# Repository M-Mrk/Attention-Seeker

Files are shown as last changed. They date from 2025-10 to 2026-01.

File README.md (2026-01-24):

# Attention-Seeker
## Overview
A multifunctional desk peripheral designed to display and alert you to notifications.

Attention-Seeker receives notifications from a companion app and displays them on its 2.8" color screen, with optional visual and audible alerts. It also features a rotary encoder and three mechanical keyboard switches for user input (no touch!).

In addition to notification-related features, it functions as a **clock**, **desk light**, and **macropad**.

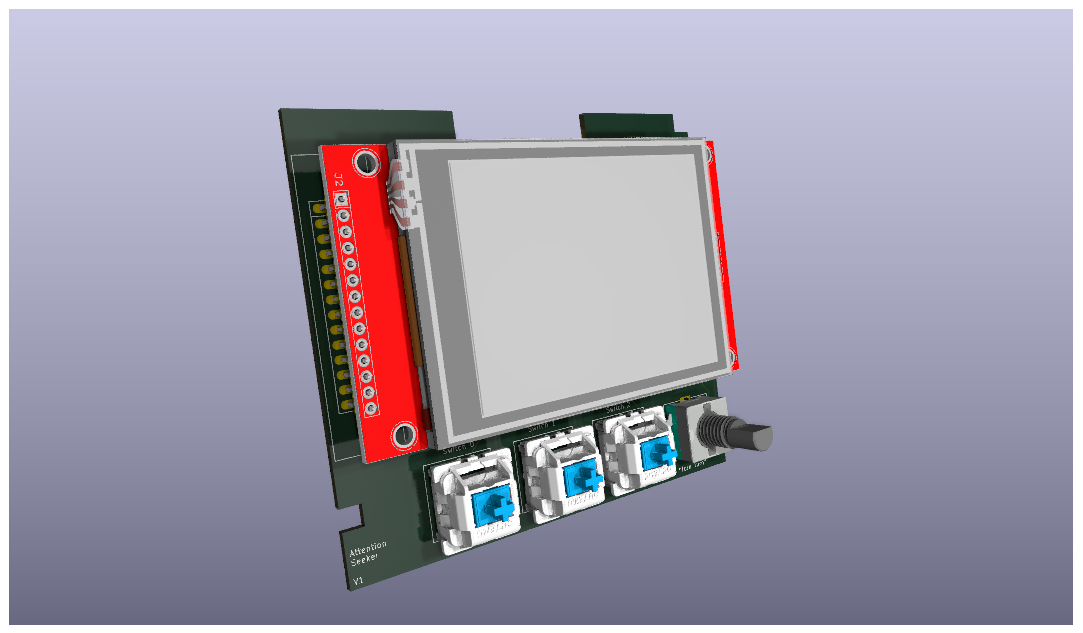
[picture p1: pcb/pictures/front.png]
Front View
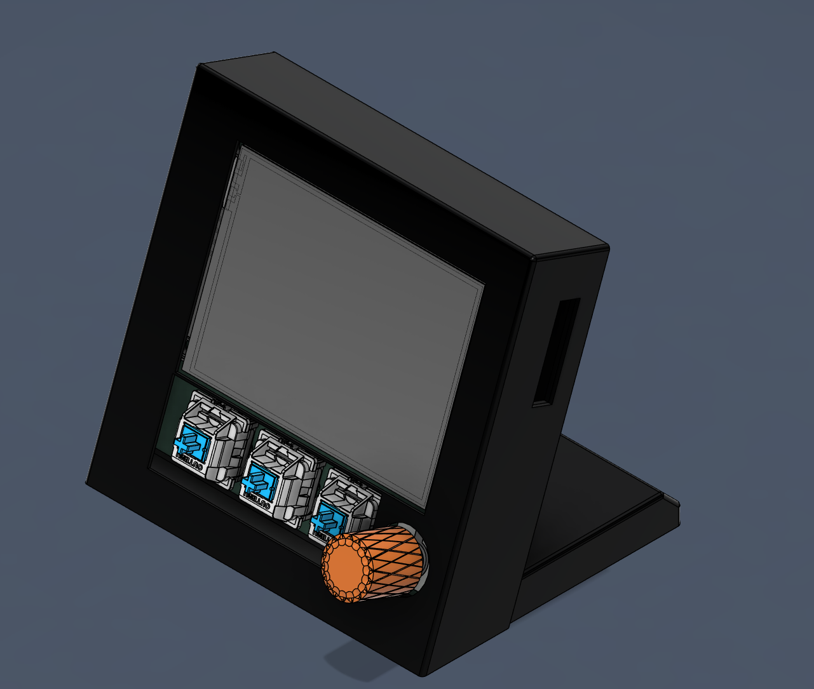
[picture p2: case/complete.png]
Semi-Assembled
 

### Why?
I often missed important notifications while zoning out or concentrating and also needed a desk light, so I built this.

### How?
- 2.8" TFT screen
- 3 mechanical keyboard switches
- Rotary encoder
- Rigid LED filament
- Buzzer
- ESP32-S3 DevKitC N16R8 CP2102
- Python companion app to run on a PC

### Example Use Cases
- **Notification:** Attention-Seeker buzzes, blinks, and displays the message.
- **Desk Light:** Toggle and dim the built-in LED for illumination.

## Features

### Notifications
Displays incoming notifications sent by the companion app with optional blinking or buzzing.

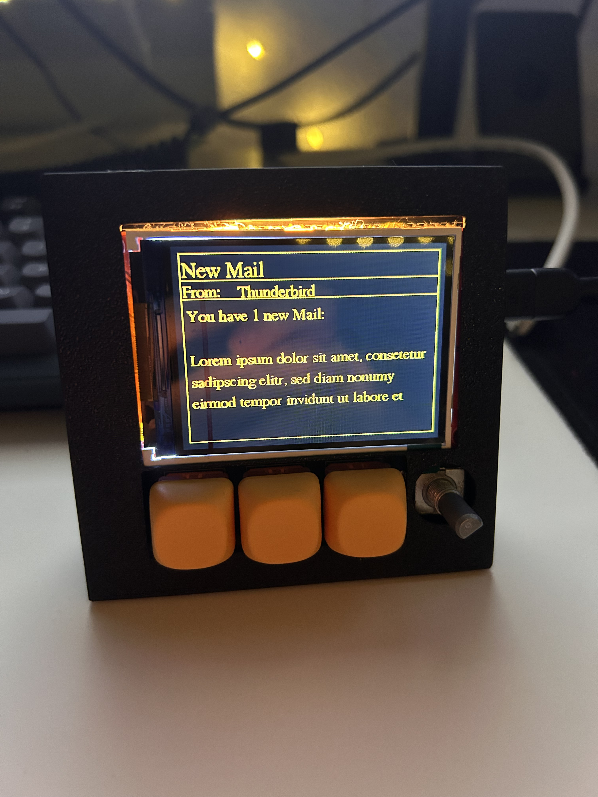
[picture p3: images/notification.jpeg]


### Clock
- Displays time
- Synced via the companion app

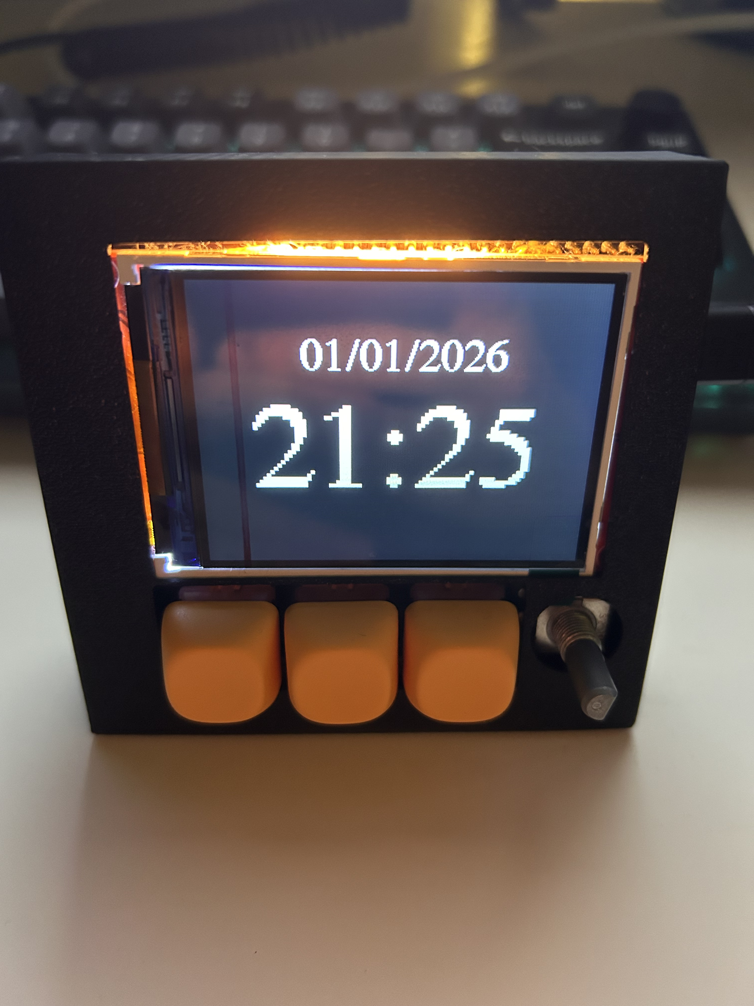
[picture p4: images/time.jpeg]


### Macropad
- 6 hotkeys

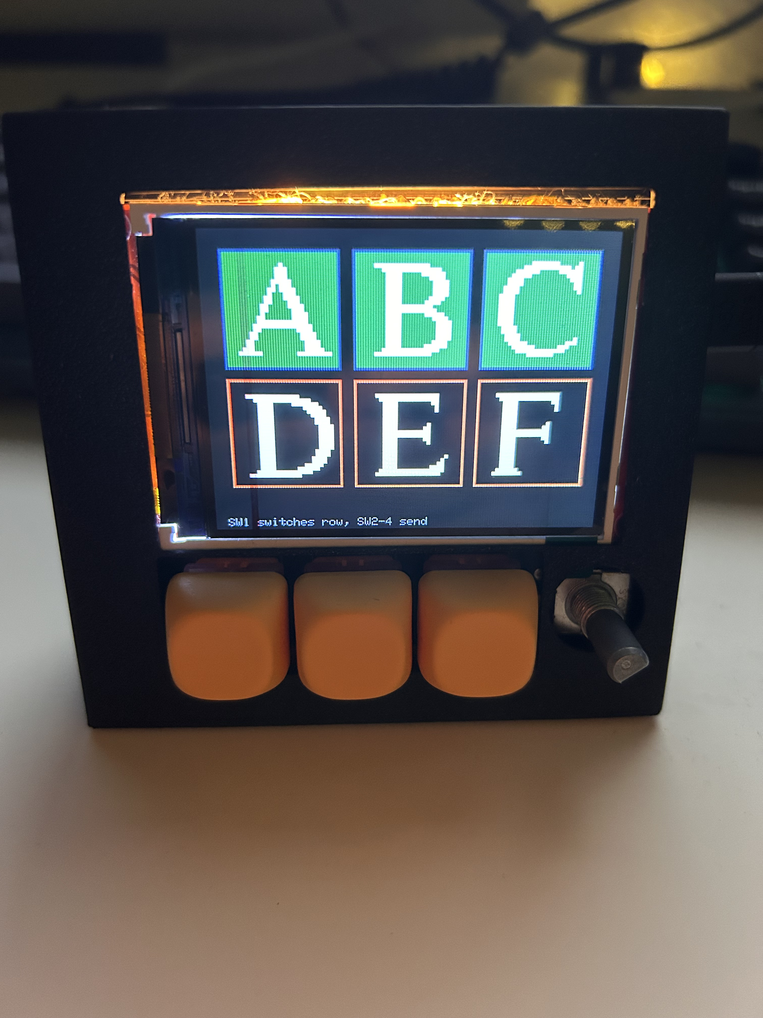
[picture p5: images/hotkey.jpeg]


### Navigation
- Mechanical keyboard switches for on-page actions
- Rotary encoder for switching between pages

### Other Features
- Dimmable desk light
- Buzzer for alerts

## Hardware

### MCU
The ESP32-S3 might be overkill but is ideal for handling the screen's pixel density, enabling fast page switching. Almost all pins are utilized, as the SPI interface for the screen consumes the majority of them.

### Lighting

#### LED Filament
The 3V filament draws about 100mA, requiring a 5V-to-3.3V LDO for power. An N-channel MOSFET drives the negative side of the LED filament.

#### Backlight
The backlight's current draw was uncertain during PCB design, so a transistor was added between it and the MCU for safety. This transistor is pulled high and can only be pulled low by the MCU.

### Other Components
All remaining components (switches, encoder, buzzer) are directly connected to the MCU.

# Build it yourself
## PCB
Order the PCB from the gerberfiles in [this zip](pcb/production/Attention-Seeker.zip). I would recommend black and the CAD files are designed for a 1.6mm thick pcb.

## Parts
Get/Order all parts from the [BOM](BOM.csv). I ordered them from reichelt and aliexpress and have included links for them. Watch out when buying the esp32 devkit, as there are countless versions and some even claim to be something different than they are.

## Soldering
First solder all smd components on the back, then the devkit and buzzer. Now you can solder on the screen based on your screen you might have to remove the sd card slot or cover it in kapton tape to be sure. I didnt have to shorten any pins, but you might have to. At last you can solder the LED on, but be very careful it snaps easily.

## Case
Print both the [top](case/case-top.3mf) and [bottom](case/case-bottom.3mf). If you dont have a cover for the rotary encoder you can also print [this](case/knob.3mf).

Place the pcb in the bottom and press fit the top on.

# Companion App
## Setup
Download [this folder](software/non-embedded/). 
Install the dependencys (if you want in a virtual environment)

`pip install -r requirements.txt`

Then just start the app
`python3 main.py`

## Device selection
Press refresh and it should automatically select your esp32. If not go through the drop down and select it manually.

## Time syncing
Press Sync Time

## Notifications
It will automatically send notifications to the device, but you can test it yourself. Press on the arrow to the left to extend the menu. Enter all your test informations and press Send JSON Notification. It should show up on the device and play a tone.

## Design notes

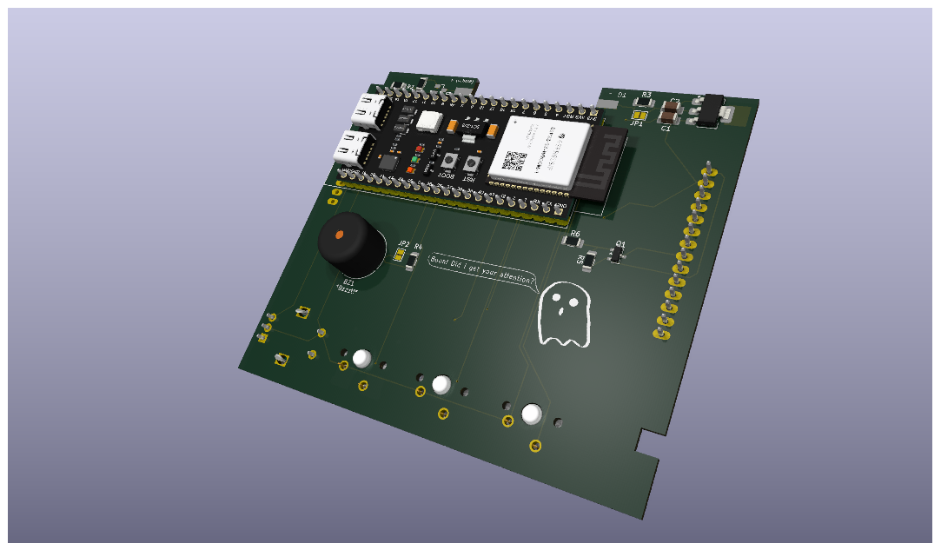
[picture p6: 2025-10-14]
pcb/pictures/back.png

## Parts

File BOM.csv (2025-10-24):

Reference | Qty | Value | DNP | Exclude from BOM | Exclude from Board | Footprint | Datasheet | Price | Link Option | Link
U1 | 1 | TFT_320x240 |  |  |  | custom_footprint:TFT-320x240 |  | 4,89€ | without touch-2.8 | https://de.aliexpress.com/item/1005006623369442.html
SW2,SW3,SW4 | 3 | SW_Push |  |  |  | Button_Switch_Keyboard:SW_Cherry_MX_1.00u_PCB | ~ | 3,09€ | 10x Tactile Milk Tea | https://de.aliexpress.com/item/1005007052813358.html
JP1,JP2 | 2 | SolderJumper_2_Open |  | Excluded from BOM |  | Jumper:SolderJumper-2_P1.3mm_Open_Pad1.0x1.5mm | ~
SW1 | 1 | RotaryEncoder_Switch |  |  |  | Rotary_Encoder:RotaryEncoder_Alps_EC12E-Switch_Vertical_H20mm | ~ | 0,99€ |  | https://de.aliexpress.com/item/1005006582140027.html
/ | 3 | Keycaps |  |  | Excluded from Board | None |  | 2,35€ | Orange/5pcs | https://de.aliexpress.com/item/1005008795444732.html
U3 | 1 | IRLML2502TRPBF |  |  |  | IRLML2502TRPBF:SOT23 |  | 0,25€ |  | https://www.reichelt.de/de/de/shop/produkt/mosfet_n-ch_20v_4_2a_0_045r_sot-23-108737
U2 | 1 | ESP32-S3-DevKitC |  |  |  | Espressif:ESP32-S3-DevKitC |  | 6,99€ | N16R8 CP2102 | https://de.aliexpress.com/item/1005007319706057.html
BZ1 | 1 | Buzzer |  |  |  | Buzzer_Beeper:Buzzer_12x9.5RM7.6 | ~ | 1,25€ |  | https://de.aliexpress.com/item/1005006132874712.html
Q1 | 1 | BSS84 |  |  |  | Package_TO_SOT_SMD:SOT-23 | http://assets.nexperia.com/documents/data-sheet/BSS84.pdf | 0,05€ |  | https://www.reichelt.de/de/de/shop/produkt/mosfet_p-ch_-60v_-0_17a_8r_sot-23-309523
U4 | 1 | AMS1117-3.3 |  |  |  | Package_TO_SOT_SMD:SOT-223-3_TabPin2 | http://www.advanced-monolithic.com/pdf/ds1117.pdf | 1,59€ | AMS1117-3.3 | https://de.aliexpress.com/item/1005002487704059.html
R3 | 1 | 3R |  |  |  | Resistor_SMD:R_1206_3216Metric_Pad1.30x1.75mm_HandSolder | ~ | 0,02€ |  | https://www.reichelt.de/de/de/shop/produkt/smd-widerstand_1206_3_3_ohm_250_mw_5_-250355
D1 | 1 | 38mm rigid LED filament |  |  |  | custom_footprint:38mm rigid LED filament | ~ | 1,19€ | 2200K Warm Yellow/38mm DC3V 10pcs | https://de.aliexpress.com/item/1005007278852273.html
R1 | 1 | 220R |  |  |  | Resistor_SMD:R_1206_3216Metric_Pad1.30x1.75mm_HandSolder | ~ | 0,02€ |  | https://www.reichelt.de/de/de/shop/produkt/smd-widerstand_1206_220_ohm_250_mw_1_-346660
C1, C2 | 2 | 10µC |  |  |  | Capacitor_SMD:C_1206_3216Metric_Pad1.33x1.80mm_HandSolder | ~ | 0,08€ |  | https://www.reichelt.de/de/de/shop/produkt/mlcc_1206_10_f_25_v_-10_x5r-409266
R2 | 1 | 10KR |  |  |  | Resistor_SMD:R_1206_3216Metric_Pad1.30x1.75mm_HandSolder | ~ | 0,02€ |  | https://www.reichelt.de/de/de/shop/produkt/smd-widerstand_1206_10_kohm_250_mw_1_-346640
R4,R6 | 2 | 100R |  |  |  | Resistor_SMD:R_1206_3216Metric_Pad1.30x1.75mm_HandSolder | ~ | 0,04€ |  | https://www.reichelt.de/de/de/shop/produkt/smd-widerstand_1206_100_ohm_250_mw_1_-346639
R5 | 1 | 100KR |  |  |  | Resistor_SMD:R_1206_3216Metric_Pad1.30x1.75mm_HandSolder | ~ | 0,08€ |  | https://www.reichelt.de/de/de/shop/produkt/mlcc_1206_10_f_25_v_-10_x5r-409266
PCB (JLCPCB) | 5 | PCB |  |  | Excluded from Board | None |  | 4,70€ | LeadFree HASL, Black(no price change)

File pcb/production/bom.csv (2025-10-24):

Designator | Footprint | Quantity | Value | LCSC Part #
BZ1 | Buzzer_12x9.5RM7.6 | 1 | Buzzer
C1, C2 | 1206 | 2 | 10µC
D1 | 38mm rigid LED filament | 1 | LED
Q1 | SOT-23 | 1 | BSS84
R1 | 1206 | 1 | 220R
R2 | 1206 | 1 | 10KR
R3 | 1206 | 1 | 3R
R4, R6 | 1206 | 2 | 100R
R5 | 1206 | 1 | 100KR
SW1 | RotaryEncoder_Alps_EC11E-Switch_Vertical_H20mm | 1 | RotaryEncoder_Switch
SW2, SW3, SW4 | SW_Cherry_MX_1.00u_PCB | 3 | SW_Push
U1 | TFT-320x240 | 1 | TFT_320x240
U2 | ESP32-S3-DevKitC | 1 | ESP32-S3-DevKitC
U3 | SOT23 | 1 | IRLML2502TRPBF
U4 | SOT-223-3_TabPin2 | 1 | AMS1117-3.3

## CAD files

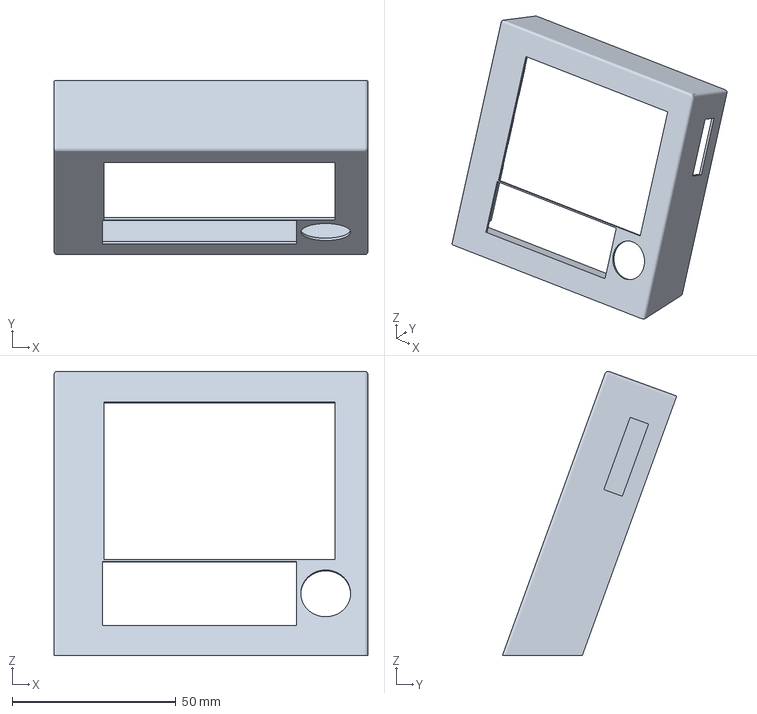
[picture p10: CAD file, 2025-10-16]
case/case-top.3mf
95.8 x 53.2 x 86.8 mm

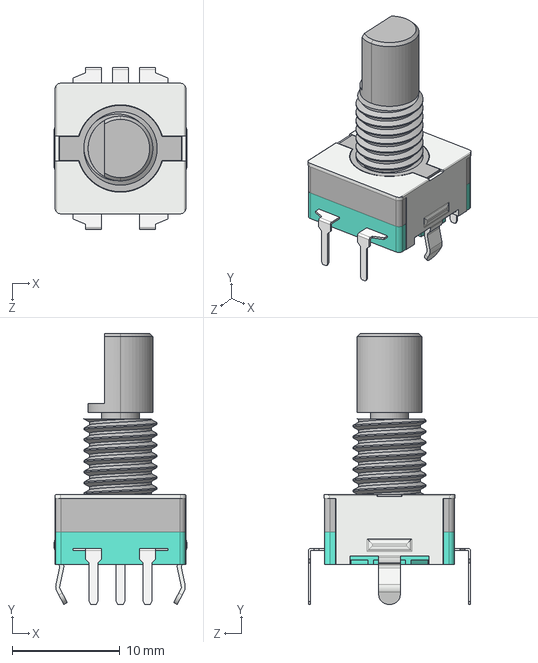
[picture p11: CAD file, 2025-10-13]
pcb/models/rotary-encoder/旋转编码器.STEP
12.3 x 25.1 x 15.0 mm

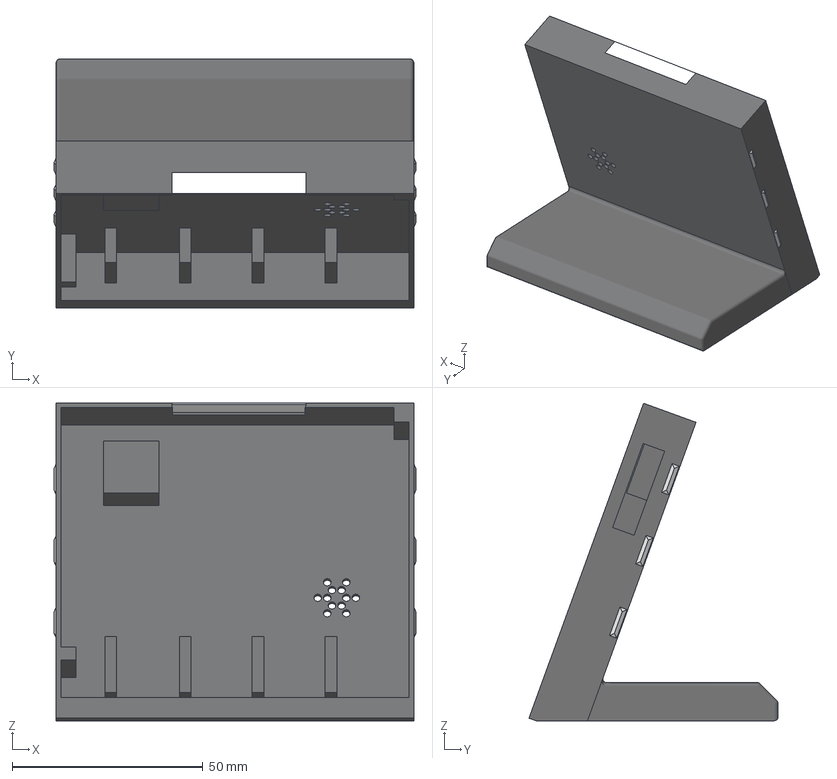
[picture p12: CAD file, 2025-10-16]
case/case-bottom.3mf
95.0 x 65.3 x 83.3 mm
Körper10
Körper11
Körper15
Körper19
Körper5
Körper6
Körper7
Körper8
Körper9

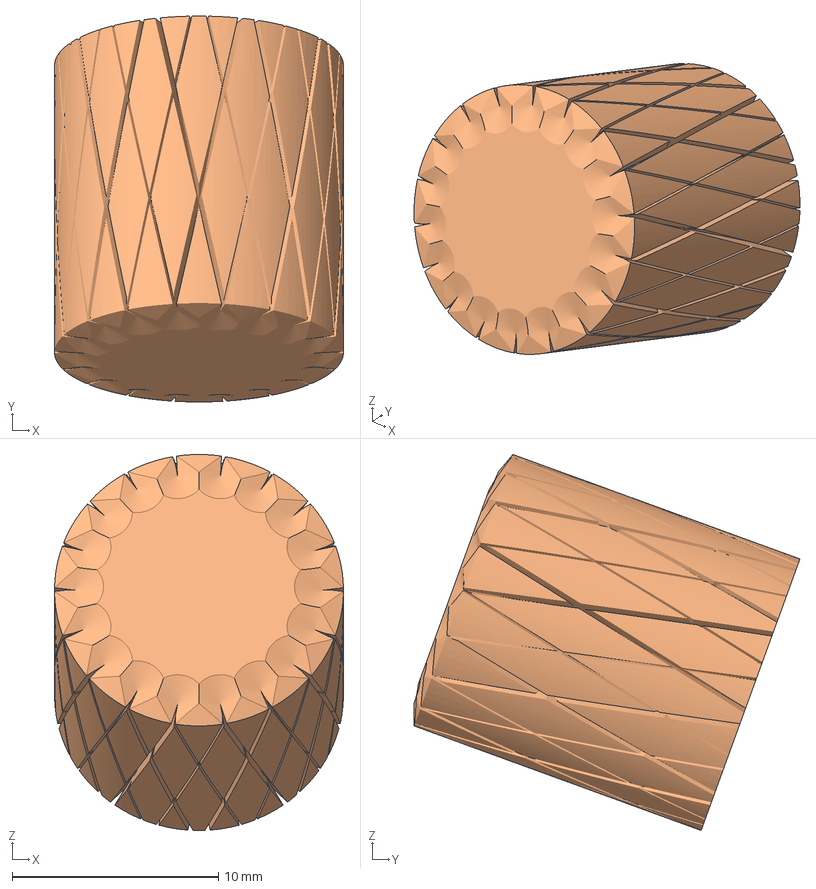
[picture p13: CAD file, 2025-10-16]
case/knob.3mf
14.0 x 18.7 x 18.2 mm

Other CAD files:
pcb/models/rotary-encoder/旋转编码器.SLDPRT

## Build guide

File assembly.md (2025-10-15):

# PCB
WIP

# Case
## Printing
Print both [top case](case/case-top.3mf) and [bottom case](case/case-bottom.3mf).
For the bottom case make sure to seperate the foot from the case.

## Assembly
- Glue the foot onto the back case
- Slide the pcb into the back case
- Press the top case onto the back case, they should snap fit together

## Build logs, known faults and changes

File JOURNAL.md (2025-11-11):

<!--
  ===================    !!READ THIS NOTICE!!   ====================
  DO NOT edit this file manually. Your changes WILL BE OVERWRITTEN!
  This journal is auto generated and updated by Hack Club Blueprint.
  To edit this file, please edit your journal entries on Blueprint.
  ==================================================================
-->

## 10/9/2025 - Designed Idea and Schematic  

In the last around 7 hours I came up with the general idea from hackpad to just a screen to now a combination of both. These changes came with a lot of hardware changes (I think I changed my MCU 3 times).

**Current Idea**
Another Desk thing/peripheral, it features should be:

- clock
- act as a small desk light
- multiple pages of macros
- display notifications and make sure to get the attention of the user (blink and buzz)

**What I now decided on:**

- 2.8" screen
- 2 keyboard switches
- a rotary encoder
- a passiv buzzer
- a 3V rigid LED filament
- esp32 s3

**What took you so long?**
This is my first bigger pcb design project, so I had to learn the hardware that it is not just connecting gpio to the next pin, e.g. I originally thought I could just hook the LED to my esp32, but in reality the current needed surpasses the range of esp so I had to learn about transistors and LDO's. Now I have a seperate LDO connected to the positive side of the LED and a transistor between gpio and GND to control the LED. Another thing that took a long time is choosing a fitting screen which has acceptable documentation to create a footprint...

**Current Schematic**
  

## 10/13/2025 4 PM - Routed the PCB  

Since the last entry I changed some things. I added a third Keyboard switch, to have even more quick options. I actually did the pcb and routed it and only changed the layout 3 times...


Next up I need to figure the BOM out and source my parts. I could also start with the software, which will need to be run on the pc to gather the notification data...

## 10/13/2025 10 PM - Finished up the pcb  

I rearranged my repo to have more clear division between software and hardware.

I created a real README

I also rendered some pictures of the pcb:



Added silkscreen descriptions and art (boo!)

And what took the most time, I did the BOM. I hate aliexpress now, why is it so hard to get just the URL and why can you not share the selected option... Well I think I am now ready to certify for the grant to get to building and coding!   

## 10/14/2025 - Finished up the pcb (x2)  

I realized my footprint for the MCU didnt account for the usb headers like I thought it did... So I had to move it alot further to the edge.

Because of this move I ofcourse had to reroute the pcb, but this time I now have one Ground loop which can not hurt. I also added a wrong 3d model for the MCU, as I cant find a fitting one but this is close enough for the modelling of the case and exchanged the BOM entry for it for a cheaper one.

My first approach for mounting the screen was to solder female headers to the board, but now I think that that would make the screen stick out too much compared to the keys. So I made the holes in the pads larger to directly fit the screen, but now I might need to trim the pins of the MCU and desolder or isolate the sd card slot of the screen.



The next step will be modelling the case  

## 10/15/2025 - Created V1 of the case  

In the last 2.8h I created the first iteration of the case for Attention-Seeker. I exported the PCB directly as a step from kicad into fusion 360 and went from there. 

The case is split up into 3 parts. The front case, back case and foot. 

Screenshot 2025-10-15 122358.png
This picture shows back case and foot. The foot glues into the back case, so that the back case can easily be 3d printed. 

The PCB will slide into the back case:
Screenshot 2025-10-15 122348.png

And then the top part will snap fit onto the back case:
Screenshot 2025-10-15 122324.png
I also designed the knob with the weird curling.

Additionally I also updated the repo with a new assembly.md and an assembly section in the ReadMe.

I think that I now do not have anything left to do without the actual hardware, so shipping time it is!

## 10/16/2025 - Redid the README  

Firstly I fixed the issue of the case missing a hole for the USB cable. Then I retook the case pictures without the grid. I also forgot to upload the 3mf file for the rotary knob, which is now also fixed



Lastly I redid the README to make it more clear and separated it into more logical sections, as well as added placeholder markdown guides for the assembly and companion app.  

## 11/8/2025 - Build the thing!  

# Getting stuff ordered
The first problem was that I somehow got so lucky as to have shipped this in between some backend stuff, so my project was lost and someone had to re-add my project to the grant queue. This already took a week.

But then I could finally order all the parts and the pcb itself, which all arrived around 2 weeks after ordering them.

# Building it!

This was my first time smd soldering, as you can probably see. But still I think I prefer smd over tht as it seems quicker. The longest part was soldering the dozens of pins from the MCU and display, but now that it is finished I am happy with the result.



# Basic testing
I used some examples from various libraries and can confirm that everything I tested works!


## 11/9/2025 - Learned stuff and failed the UI controller  

# Installation
At first I had to learn how to setup plattformIO and needed to configure it for the esp32-s3-devkitc-n16r8. The next hoop was figuring out linux usb permissions which were easy enough but got me stuck on the serial monitor for a while, as I first temporarily made my user owner of the port, which allowed uploading, but the Serial monitor didnt work reliably for some reason. After I added my user to the uucp and logged in and out everything worked.

# Libraries
The next step was to further test my components on PIO and choose an appropriate library for the display. I first tried tft_espi but quickly got frustrated with the user_setup.h file (skill issue) so I switched to the easier adafruit gfx, which worked great.

# C++ OOP
I had experience with C++ and other OOP languages before, but not C++ OOP, so I had to take a small excourse to learn that. I then wanted to build something, like this sketch
sketch

I was not fluent enough in C++ for this so I did take some help from AI. This worked at first but as soon as I used any variables it would compile but the MCU would always panic at drawing (which was a first to me). So I think I will rebuild it less abstract and with more familiar methods.

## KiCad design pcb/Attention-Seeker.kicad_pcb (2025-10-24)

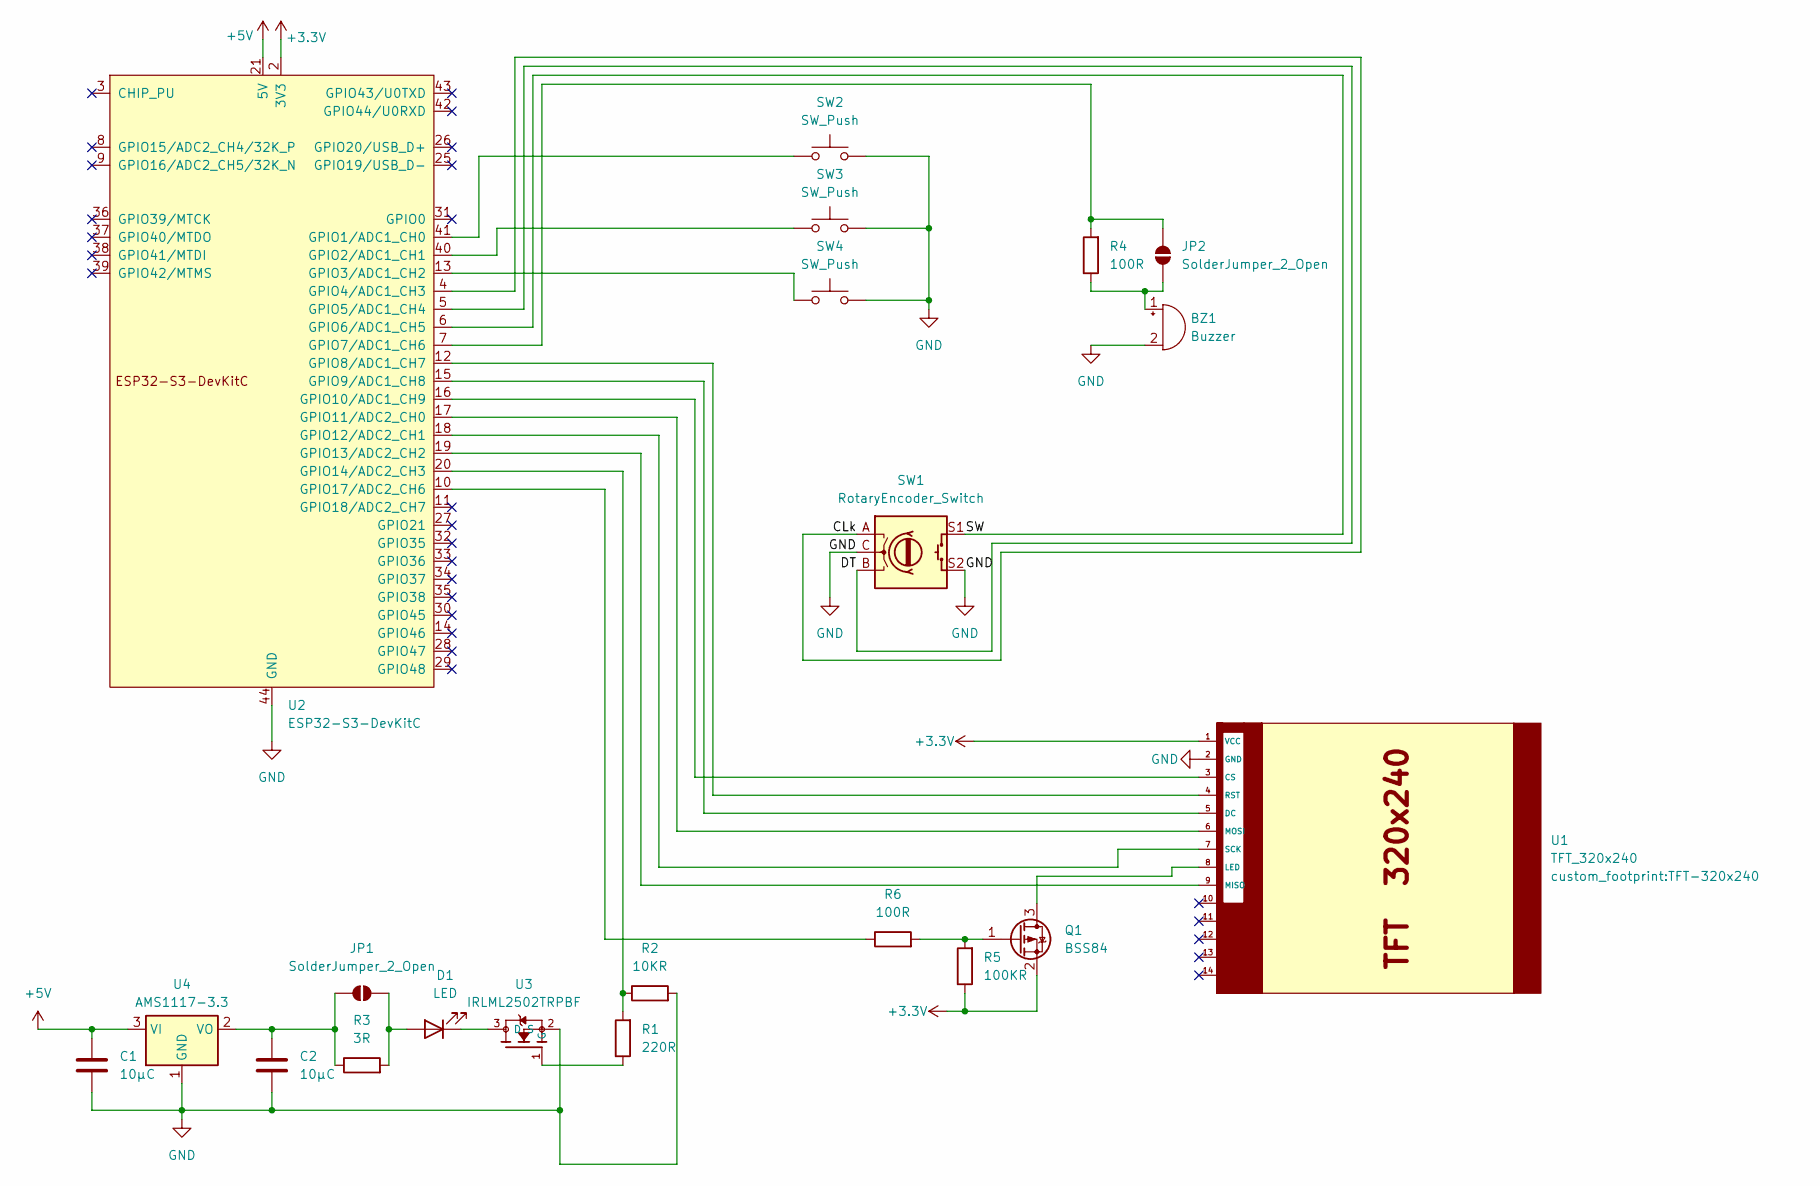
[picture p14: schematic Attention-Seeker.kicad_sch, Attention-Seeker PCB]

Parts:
BZ1: Buzzer; Buzzer_12x9.5RM7.6
C1, C2: 10µC; C_1206_3216Metric_Pad1.33x1.80mm_HandSolder
D1: LED; 38mm rigid LED filament
JP1, JP2: SolderJumper_2_Open; SolderJumper-2_P1.3mm_Open_Pad1.0x1.5mm
Q1: BSS84; SOT-23
R1: 220R; R_1206_3216Metric_Pad1.30x1.75mm_HandSolder
R2: 10KR; R_1206_3216Metric_Pad1.30x1.75mm_HandSolder
R3: 3R; R_1206_3216Metric_Pad1.30x1.75mm_HandSolder
R4, R6: 100R; R_1206_3216Metric_Pad1.30x1.75mm_HandSolder
R5: 100KR; R_1206_3216Metric_Pad1.30x1.75mm_HandSolder
SW1: RotaryEncoder_Switch; RotaryEncoder_Alps_EC11E-Switch_Vertical_H20mm
SW2, SW3, SW4: SW_Push; SW_Cherry_MX_1.00u_PCB
U1: TFT_320x240; TFT-320x240
U2: ESP32-S3-DevKitC
U3: IRLML2502TRPBF; SOT23
U4: AMS1117-3.3; SOT-223-3_TabPin2

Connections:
+3.3V: Q1.2 (S), R5.1, U1.1 (VCC), U2.1 (3V3), U2.2 (3V3)
+5V: C1.2, U2.21 (5V), U4.3 (VI)
/CLk: SW1.A, U2.4 (GPIO4/ADC1_CH3)
/DT: SW1.B, U2.5 (GPIO5/ADC1_CH4)
/SW: SW1.S1, U2.6 (GPIO6/ADC1_CH5)
GND: BZ1.2 (-), C1.1, C2.1, R2.2, SW1.C, SW1.S2, SW2.2, SW3.2, SW4.2, U1.2 (GND), U2.22 (GND), U2.23 (GND), U2.24 (GND), U2.44 (GND), U3.2 (S), U4.1 (GND)
unnamed: BZ1.1 (+), JP2.2 (B), R4.1
unnamed: D1.2 (A), JP1.2 (B), R3.2
unnamed: D1.1 (K), U3.3 (D)
unnamed: C2.2, JP1.1 (A), R3.1, U4.2 (VO)
unnamed: JP2.1 (A), R4.2, U2.7 (GPIO7/ADC1_CH6)
unnamed: Q1.3 (D), U1.8 (LED)
unnamed: Q1.1 (G), R5.2, R6.2
unnamed: U1.3 (CS), U2.16 (GPIO10/ADC1_CH9)
unnamed: U1.5 (DC), U2.15 (GPIO9/ADC1_CH8)
unnamed: U1.9 (MISO), U2.19 (GPIO13/ADC2_CH2)
unnamed: U1.6 (MOSI), U2.17 (GPIO11/ADC2_CH0)
unnamed: U1.4 (RST), U2.12 (GPIO8/ADC1_CH7)
unnamed: U1.7 (SCK), U2.18 (GPIO12/ADC2_CH1)
unnamed: SW2.1, U2.41 (GPIO1/ADC1_CH0)
unnamed: SW3.1, U2.40 (GPIO2/ADC1_CH1)
unnamed: SW4.1, U2.13 (GPIO3/ADC1_CH2)
unnamed: R1.2, R2.1, U2.20 (GPIO14/ADC2_CH3)
unnamed: R6.1, U2.10 (GPIO17/ADC2_CH6)
unnamed: R1.1, U3.1 (G)

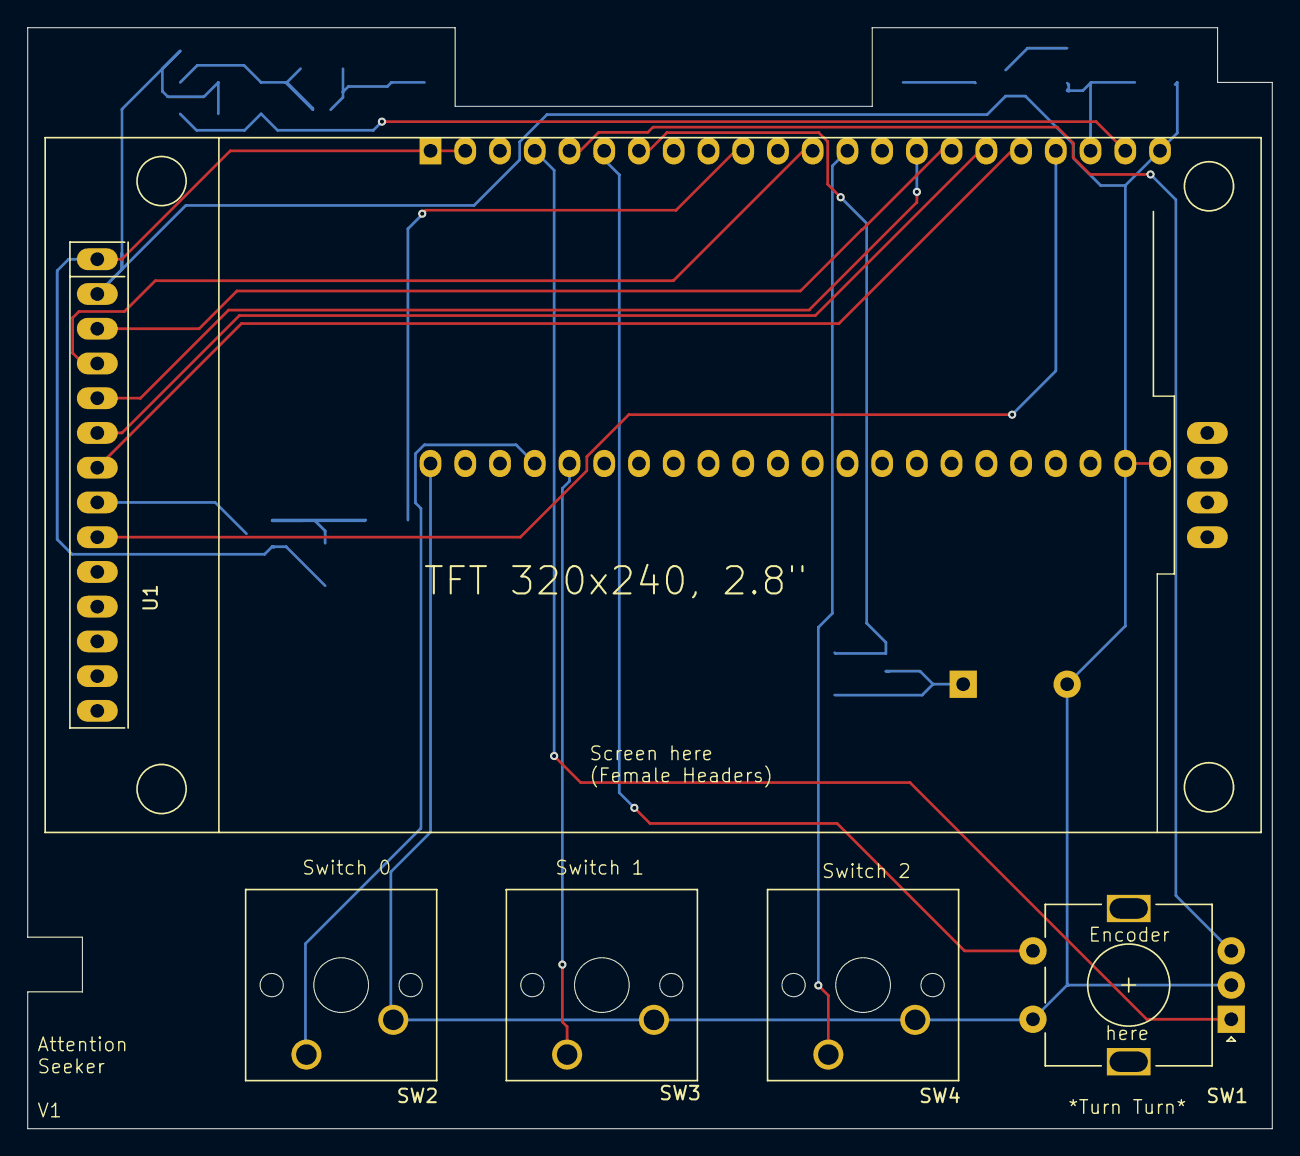
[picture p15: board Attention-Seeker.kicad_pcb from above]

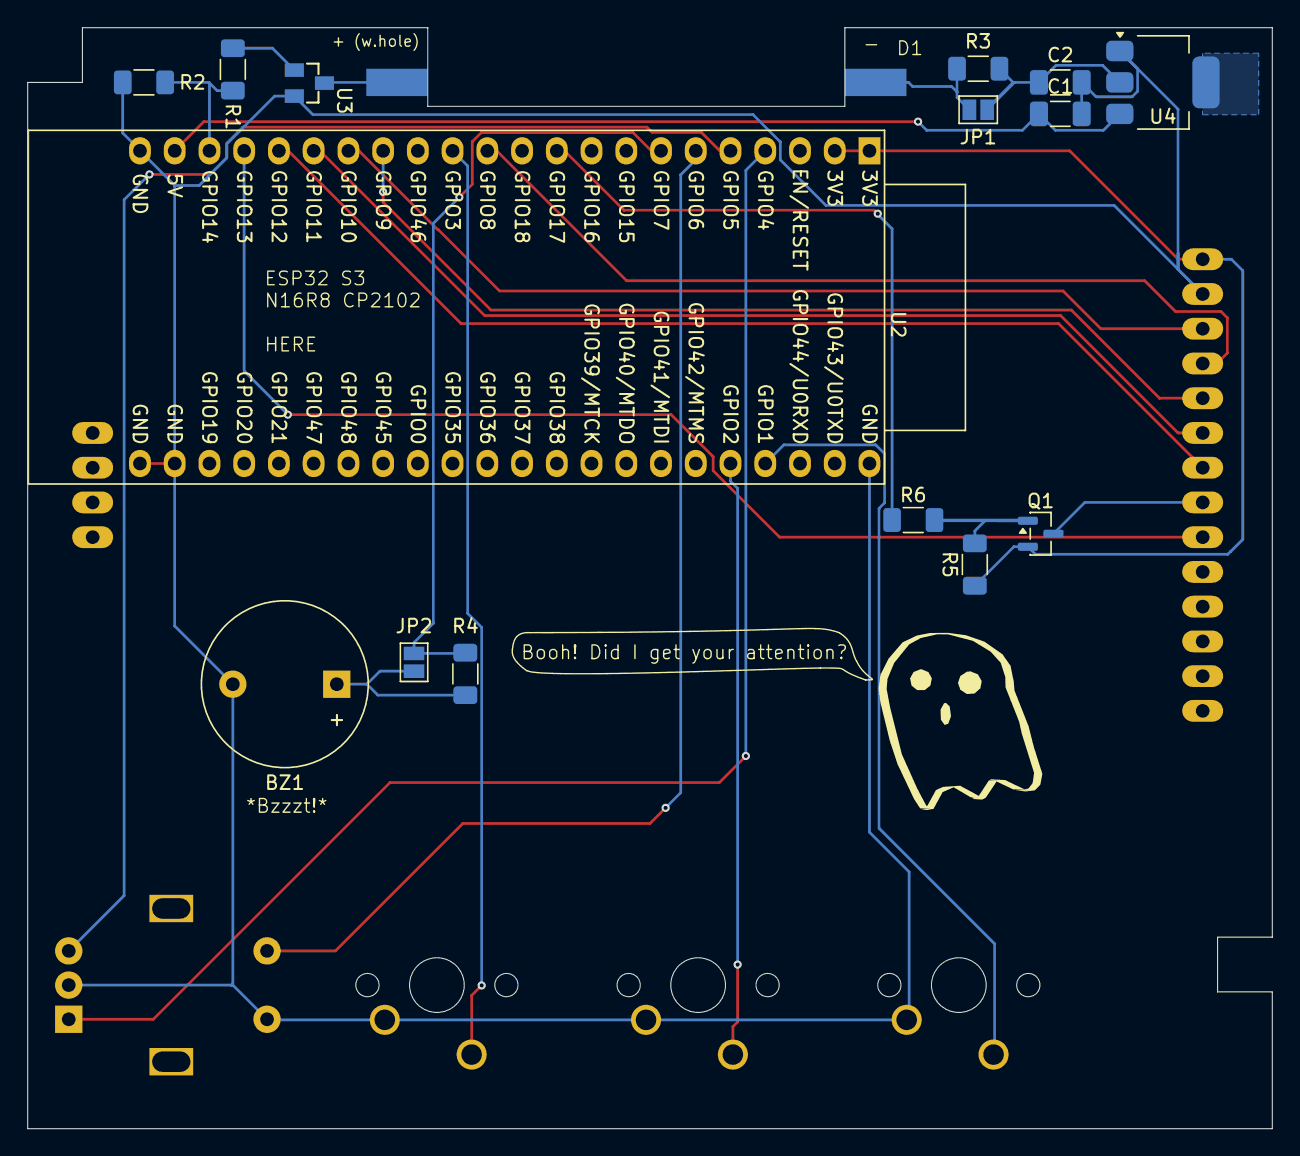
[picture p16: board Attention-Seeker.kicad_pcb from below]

Board: 2 copper layers, 91.0 x 80.5 mm, 21 parts (16 on the bottom side), 25 nets.

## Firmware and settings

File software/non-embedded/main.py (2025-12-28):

import sys
import asyncio
from PySide6.QtWidgets import QApplication, QMainWindow, QLabel, QVBoxLayout, QHBoxLayout, QWidget, QComboBox, QPushButton, QTextEdit, QLineEdit, QToolButton
from PySide6.QtCore import Qt, QThread, Signal

import json
import threading
import datetime
import serial
import serial.tools.list_ports
from dbus_next.aio import MessageBus
from dbus_next import MessageType, Message

class MainWindow(QMainWindow):
    def __init__(self):
        super().__init__()

        self.setWindowTitle("Attention Seeker")

        # Main layout
        layout = QVBoxLayout()

        # Section 1: Dropdown with label and refresh button
        dropdown_label = QLabel("Select Attention-Seeker port:")
        dropdown_label.setAlignment(Qt.AlignmentFlag.AlignLeft)
        self.dropdown = QComboBox()
        self.refresh_button = QPushButton("Refresh")
        self.refresh_button.clicked.connect(self.refresh_ports)

        # Populate the dropdown initially
        self.populate_ports()

        # Create a horizontal layout for the dropdown and refresh button
        dropdown_layout = QHBoxLayout()
        dropdown_layout.addWidget(self.dropdown)
        dropdown_layout.addWidget(self.refresh_button)

        layout.addWidget(dropdown_label)
        layout.addLayout(dropdown_layout)

        # Section 2: Buttons
        self.button1 = QPushButton("Sync Time")
        self.button3 = QPushButton("Clear output")
        self.button1.clicked.connect(self.send_time_sync)
        self.button3.clicked.connect(lambda: self.clear_output())
        layout.addWidget(self.button1)
        layout.addWidget(self.button3)

        # JSON notification inputs
        # Collapsible notification form toggle
        self.toggle_notify_button = QToolButton()
        self.toggle_notify_button.setText("Send test notification")
        self.toggle_notify_button.setCheckable(True)
        self.toggle_notify_button.setChecked(False)
        self.toggle_notify_button.setArrowType(Qt.RightArrow)
        layout.addWidget(self.toggle_notify_button)

        origin_label = QLabel("Origin:")
        self.origin_input = QLineEdit()
        self.origin_input.setPlaceholderText("e.g. AttentionSeeker")

        title_label = QLabel("Title:")
        self.title_input = QLineEdit()
        self.title_input.setPlaceholderText("Notification title")

        body_label = QLabel("Body:")
        self.body_input = QTextEdit()
        self.body_input.setPlaceholderText("Notification body text")

        self.send_json_button = QPushButton("Send JSON Notification")
        self.send_json_button.clicked.connect(self.send_notification_json)

        # Put the form into a container so we can collapse it
        self.notify_form = QWidget()
        form_layout = QVBoxLayout()
        form_layout.setContentsMargins(12, 0, 0, 0)
        form_layout.addWidget(origin_label)
        form_layout.addWidget(self.origin_input)
        form_layout.addWidget(title_label)
        form_layout.addWidget(self.title_input)
        form_layout.addWidget(body_label)
        form_layout.addWidget(self.body_input)
        form_layout.addWidget(self.send_json_button)
        self.notify_form.setLayout(form_layout)
        self.notify_form.setVisible(False)  # collapsed by default
        layout.addWidget(self.notify_form)

        # Toggle behaviour
        def _toggle_notify(checked: bool):
            self.notify_form.setVisible(checked)
            self.toggle_notify_button.setArrowType(Qt.DownArrow if checked else Qt.RightArrow)

        self.toggle_notify_button.toggled.connect(_toggle_notify)

        # Section 3: Text output box
        self.text_output = QTextEdit()
        self.text_output.setReadOnly(True)
        layout.addWidget(self.text_output)

        # Set central widget
        container = QWidget()
        container.setLayout(layout)
        self.setCentralWidget(container)

        # Serial reading thread handle
        self.serial_thread = None

        # System notification listener
        self.notification_listener = NotificationListener()
        self.notification_listener.notification_received.connect(self.handle_system_notification)
        self.notification_listener.error.connect(lambda e: self.update_output(f"Notification listener error: {e}"))
        self.notification_listener.start()

        # React to port selection changes
        self.dropdown.currentIndexChanged.connect(self.on_port_changed)

        # Start reading from the initially selected port (if any)
        self.on_port_changed(self.dropdown.currentIndex())

    def populate_ports(self):
        self.dropdown.clear()
        for port, desc in get_serial_ports():
            self.dropdown.addItem(f"{port} — {desc}", port)

    def refresh_ports(self):
        self.populate_ports()


    def update_output(self, message=None):
        if message is None:
            message = f"Selected: {self.dropdown.currentText()}"
        self.text_output.append(message)

    def clear_output(self):
        self.text_output.clear()

    def send_notification_json(self):
        origin = self.origin_input.text().strip()
        title = self.title_input.text().strip()
        body = self.body_input.toPlainText().strip()

        if not origin:
            self.update_output("Please set origin before sending.")
            return

        payload = {
            "type": "notification",
            "origin": origin,
            "title": title,
            "body": body,
        }

        self._send_payload(payload, "Sent", "Failed to send")

    def send_time_sync(self):
        # send current computer time/date as JSON
        ts = datetime.datetime.now().isoformat()

        payload = {"type": "time_sync", "timestamp": ts}
        self._send_payload(payload, "Sent time sync", "Failed to send time sync")

    def _send_payload(self, payload: dict, success_label: str, failure_label: str):
        try:
            json_str = json.dumps(payload, ensure_ascii=False)
        except Exception as e:
            self.update_output(f"JSON serialization error: {e}")
            return False

        data = (json_str + "\n").encode("utf-8")

        if self.serial_thread is None:
            self.update_output("No serial connection to send to.")
            return False

        try:
            self.serial_thread.write(data)
            self.update_output(f"{success_label}: {json_str}")
            return True
        except Exception as e:
            self.update_output(f"{failure_label}: {e}")
            return False

    def on_port_changed(self, index):
        port = self.dropdown.itemData(index)
        if not port or port == "None found":
            self.stop_serial_reader()
            self.update_output("No serial device selected.")
            return
        self.start_serial_reader(port)

    def start_serial_reader(self, port, baud=115200):
        self.stop_serial_reader()
        self.serial_thread = SerialReader(port, baud)
        self.serial_thread.data_received.connect(lambda s: self.update_output(s))
        self.serial_thread.error.connect(lambda e: self.update_output(f"Serial error: {e}"))
        self.serial_thread.finished.connect(lambda: self.update_output(f"Serial reader stopped for {port}"))
        self.serial_thread.start()
        self.update_output(f"Connected to {port}")

    def stop_serial_reader(self):
        if self.serial_thread is not None:
            try:
                self.serial_thread.stop()
            except Exception:
                pass
            self.serial_thread = None

    def closeEvent(self, event):
        self.stop_serial_reader()
        if self.notification_listener is not None:
            try:
                self.notification_listener.stop()
                self.notification_listener.wait(1500)
            except Exception:
                pass
        super().closeEvent(event)

    def handle_system_notification(self, payload: dict):
        origin = payload.get("origin") or "System"
        title = payload.get("title") or ""
        body = payload.get("body") or ""
        urgency = payload.get("urgency")

        preview = f"[OS Notification] {origin}: {title}"
        if body:
            preview = f"{preview} — {body}"
        if urgency is not None:
            preview = f"{preview} (urgency={urgency})"

        self.update_output(preview)
        self._send_payload(payload, "Forwarded notification", "Failed to forward notification")

def get_serial_ports():
    ports = serial.tools.list_ports.comports()
    if not ports:
        return [("None found", "Try to refresh")]

    def _is_likely_esp32(port) -> bool:
        dev = port.device or ""
        # Linux: ignore onboard UARTs (ttyS*), keep USB/ACM devices
        if dev.startswith("/dev/ttyS"):
            return False
        if "ttyUSB" in dev or "ttyACM" in dev:
            return True
        # VID for Espressif is usually 0x303A when using TinyUSB
        if port.vid and port.vid == 0x303A:
            return True
        # Fallback: match manufacturer/product strings
        m = (port.manufacturer or "").lower()
        prod = (port.product or "").lower()
        return "esp" in m or "tinyusb" in prod or "esp" in prod

    filtered = [p for p in ports if _is_likely_esp32(p)]
    target = filtered if filtered else ports  # show all if filter empty

    out = []
    for p in target:
        desc = p.description or ""
        if p.manufacturer:
            desc = f"{desc} ({p.manufacturer})" if desc else p.manufacturer
        out.append((p.device, desc))

    return out if out else [("None found", "Try to refresh")]


class NotificationListener(QThread):
    notification_received = Signal(dict)
    error = Signal(str)

    def __init__(self):
        super().__init__()
        self._stop_evt = threading.Event()

    def stop(self):
        self._stop_evt.set()

    def run(self):
        try:
            asyncio.run(self._run())
        except Exception as e:
            self.error.emit(str(e))

    async def _run(self):
        try:
            bus = await MessageBus().connect()
        except Exception as e:
            self.error.emit(f"Failed to connect to D-Bus: {e}")
            return

        def _handle_message(message):
            if message.message_type != MessageType.METHOD_CALL:
                return False
            if message.interface != "org.freedesktop.Notifications" or message.member != "Notify":
                return False

            args = message.body or []
            app_name = args[0] if len(args) > 0 else ""
            summary = args[3] if len(args) > 3 else ""
            body = args[4] if len(args) > 4 else ""
            hints = args[6] if len(args) > 6 else {}

            urgency = None
            try:
                if isinstance(hints, dict):
                    urgency = hints.get("urgency")
            except Exception:
                urgency = None

            payload = {
                "type": "notification",
                "origin": app_name or "System",
                "title": summary or "",
                "body": body or "",
            }
            if urgency is not None:
                payload["urgency"] = urgency

            self.notification_received.emit(payload)
            return False

        bus.add_message_handler(_handle_message)

        match_rule = "type='method_call',interface='org.freedesktop.Notifications',member='Notify'"

        async def _add_match(rule: str):
            msg = Message(
                destination="org.freedesktop.DBus",
                path="/org/freedesktop/DBus",
                interface="org.freedesktop.DBus",
                member="AddMatch",
                signature="s",
                body=[rule],
            )
            reply = await bus.call(msg)
            if reply.message_type == MessageType.ERROR:
                raise RuntimeError(reply.body[0] if reply.body else reply.error_name)

        # Try with eavesdrop first (may be blocked by bus policy), then fall back without it
        try:
            await _add_match(match_rule + ",eavesdrop='true'")
        except Exception as e1:
            self.error.emit(f"Notify subscription with eavesdrop failed: {e1}; retrying without eavesdrop")
            try:
                await _add_match(match_rule)
            except Exception as e2:
                self.error.emit(f"Failed to subscribe to notifications: {e2}")
                bus.disconnect()
                return

        try:
            while not self._stop_evt.is_set():
                await asyncio.sleep(0.25)
        finally:
            try:
                bus.disconnect()
            except Exception:
                pass


class SerialReader(QThread):
    data_received = Signal(str)
    error = Signal(str)

    def __init__(self, port, baud=115200):
        super().__init__()
        self.port = port
        self.baud = baud
        self._running = True
        self.ser = None
        self._write_lock = threading.Lock()

    def run(self):
        try:
            self.ser = serial.Serial(self.port, self.baud, timeout=0.5)
        except Exception as e:
            self.error.emit(str(e))
            return

        try:
            while self._running:
                try:
                    line = self.ser.readline()
                except Exception as e:
                    self.error.emit(str(e))
                    break
                if not line:
                    continue
                try:
                    text = line.decode(errors='replace').rstrip('\r\n')
                except Exception:
                    text = repr(line)
                text = "[Device]: " + text
                self.data_received.emit(text)
        finally:
            try:
                if self.ser and self.ser.is_open:
                    self.ser.close()
            except Exception:
                pass

    def stop(self):
        self._running = False
        self.wait(1000)

    def write(self, data: bytes):
        if not isinstance(data, (bytes, bytearray)):
            raise TypeError("data must be bytes")
        with self._write_lock:
            if not self.ser or not self.ser.is_open:
                raise RuntimeError("Serial port not open")
            try:
                self.ser.write(data)
            except Exception as e:
                self.error.emit(str(e))
                raise

if __name__ == "__main__":
    app = QApplication(sys.argv)

    window = MainWindow()
    window.show()

    sys.exit(app.exec())

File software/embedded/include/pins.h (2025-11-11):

#ifndef PINS_H
#define PINS_H

#include <Arduino.h>

// Display
constexpr int BACKLIGHT_PIN = 17;

// constexpr int TFT_DC = 9;
// constexpr int TFT_CS = 10;
// constexpr int TFT_MOSI = 11;
// constexpr int TFT_CLK = 12;
// constexpr int TFT_RST = 8;
// constexpr int TFT_MISO = 13;

// Mechanical switches / kbd
constexpr int SW2_PIN = 1, SW3_PIN = 2, SW4_PIN = 3; 

// Buzzer
constexpr int BUZZER_PIN = 7;

// Rotary encoder
constexpr int ROTARY_CLK_PIN = 4;
constexpr int ROTARY_DT_PIN = 5;
constexpr int ROTARY_SW_PIN = 6;

// Light
constexpr int LED_PIN = 14;
constexpr int BUILD_IN_LED_PIN = 48;

#endif

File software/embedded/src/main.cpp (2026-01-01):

#include <Arduino.h>
#include <ESP32Time.h>

#include "pins.h"

// Display
#include "DisplayManager.h"
#include "LightManager.h"
#include "MelodyManager.h"
#include "UsbHandler.h"
#include "screens/HotkeyScreen.h"
#include "screens/SettingsScreen.h"
#include "screens/TimeScreen.h"

DisplayManager displayManager;
TimeScreen timeScreen;
HotkeyScreen hotkeyScreen;
SettingsScreen settingsScreen;
ESP32Time rtc(3600);

MelodyManager melodyManager;

// Input
#include "physicalInput.h"

void displayDrawTask(void *pvParameters) {
  QueueHandle_t inputQueue = static_cast<QueueHandle_t>(pvParameters);
  for (;;) {
    InputEvent event;
    if (xQueueReceive(inputQueue, &event, 0)) {
      displayManager.handleInput(event);
    }
    displayManager.draw();
    vTaskDelay(pdMS_TO_TICKS(16)); // Approx ~60 FPS
  };
};

QueueHandle_t inputQueue;

void setup(void) {
  usbHandler.setup();
  Serial.println("Attention Seeker starting...");

  // Input
  inputQueue = xQueueCreate(10, sizeof(InputEvent));
  initInputs();
  startInputTasks(inputQueue);

  // Melody
  melodyManager.init(BUZZER_PIN);

  // Light
  lightManager.init();

  // Display
  displayManager.init();
  // register screens and select settings screen
  displayManager.registerScreen(&timeScreen, 0);
  displayManager.registerScreen(&hotkeyScreen, 1);
  displayManager.registerScreen(&settingsScreen, 2);
  // use registered index for initial screen (if registration failed idxSettings
  // may be -1)
  displayManager.setScreen(0);
  xTaskCreatePinnedToCore( // Start display drawing task
      displayDrawTask, "DisplayDrawTask", 4096, inputQueue, 1, nullptr, 1);

  // RTC
  rtc.setTime(30, 24, 15, 17, 1, 2021); // 15:24:30 17.01.2021
  // TODO: remember time somehow across reboots

  usbHandler.startListening();

  Serial.println("Attention Seeker initialized");

  // Play startup sound
  melodyManager.playSuccess();

  lightManager.setLightLevel(125); // set medium light level
}

void loop() {}

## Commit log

2025-10-09 first version of schematic
    [Attention-Seeker.kicad_pcb, Attention-Seeker.kicad_sch]
2025-10-13 finished v1 of pcb
    [Attention-Seeker.kicad_pcb, Attention-Seeker.kicad_sch]
2025-10-13 Updated README. Added BOM and 3d Model
    [Attention-Seeker.kicad_pcb, BOM.csv, 旋转编码器.SLDPRT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]
2025-10-13 Updated Readme, gerber and added pcb price to BOM
    [BOM.csv, bom.csv, designators.csv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]
2025-10-13 moved BOM.csv to root for blueprint requirements
    [BOM.csv]
2025-10-14 changed pads for MCU and screen to fit square pins, 1mm hole diameter. Found cheaper MCU alternative. Moved MCU more to the edge and rerouted accordingly.
    [Attention-Seeker.kicad_pcb, BOM.csv, positions.csv]
2025-10-14 Fixed some routing weirdness (unessecary paths) and added nearly fitting model for the mcu. Updated pictures and 3d Model
    [Attention-Seeker.kicad_pcb]
2025-10-14 updated .gitignore to ignore temporary kicad edit files
2025-10-15 Added V1 of case, added assembly.md and reference to it in readme
    [case-bottom.3mf, case-top.3mf]
2025-10-16 redid the case pictures without grid and refactored the README
    [case-bottom.3mf, case-top.3mf, knob.3mf]
2025-10-16 updated rotary encoder footprint and sourced smd parts from other source
    [Attention-Seeker.kicad_pcb, Attention-Seeker.kicad_sch, BOM.csv]
2025-10-24 fixed critical issue with cap alignment
    [Attention-Seeker.kicad_pcb, Attention-Seeker.kicad_sch, BOM.csv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]
2025-11-11 switched to TFT_eSPI and improved display manager
2026-01-01 Notification menu now wraps text correctly and updated ReadMe
    [UsbHandler.cpp, main.cpp]
